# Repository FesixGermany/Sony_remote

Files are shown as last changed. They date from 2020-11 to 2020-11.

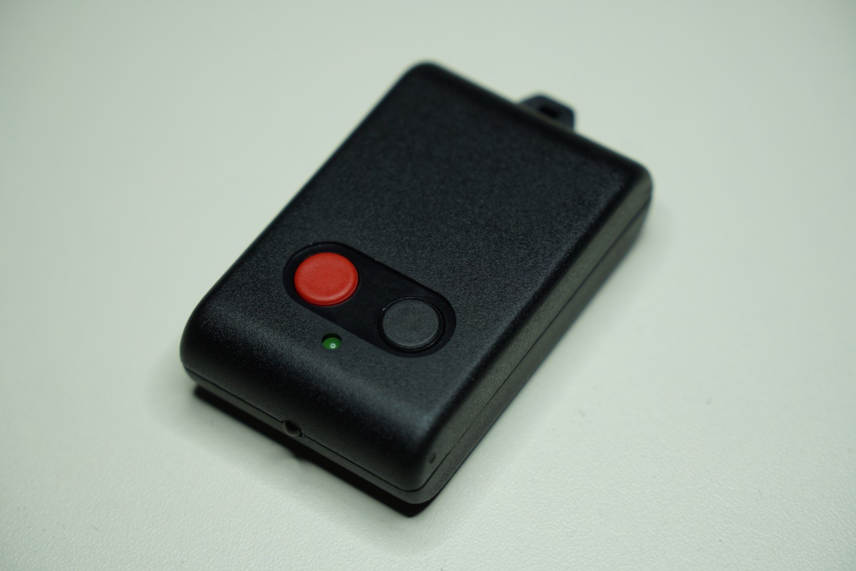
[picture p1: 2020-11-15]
documentation/Remote_case.jpg

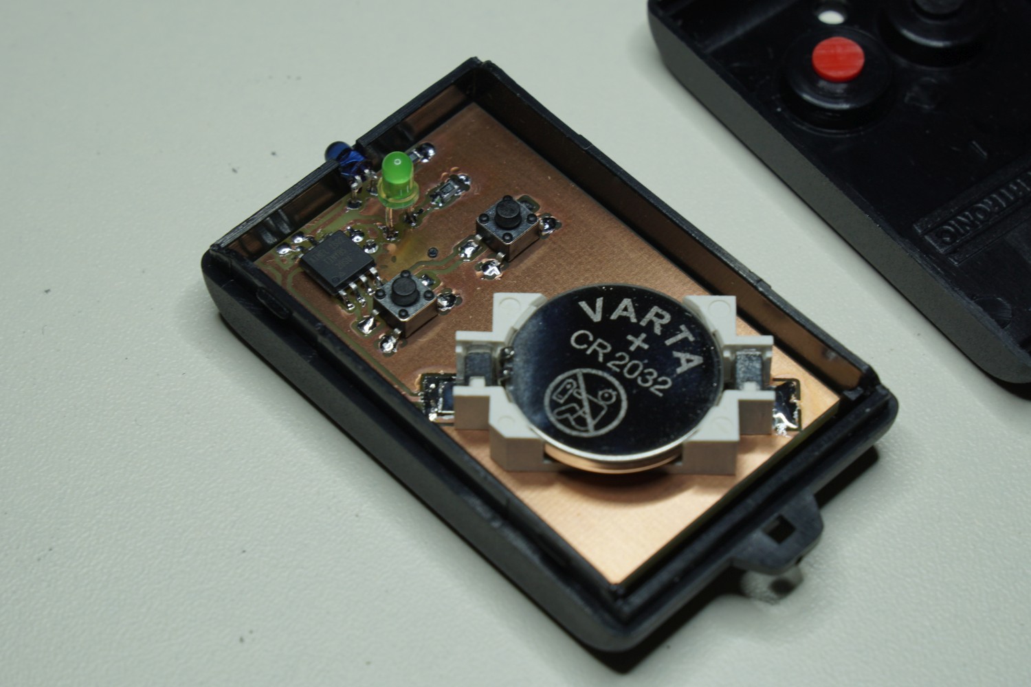
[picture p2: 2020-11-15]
documentation/Remote_inner.jpg

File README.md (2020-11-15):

I wanted a remote control for my Sony a6500 camera which has an IR receiver. There is a dedicated remote control with tons of buttons I don't need so I thought this would be a nice little project as all I need is a button for instant action and for a two second delay.  
Additionally the command for starting and stopping video recording is in the firmware so the functionality of the buttons can be changed.  
Exchange `ShutterCode` or `TwoSecsCode` with `VideoCode`.

```c
#define ButtonRightCode ShutterCode
#define ButtonLeftCode	TwoSecsCode
```

The whole circuit is powered by a 2032 button cell.  
The controller generates the necessary 40kHz modulation and sends the command set in the firmware when the button is pressed. As long as the command is transmitted the green LED is lit.
After that the controller goes into sleep mode to save battery.

In order to work with the camera the remote function needs to be enabled in the system menu.

The original code is from http://www.technoblogy.com/show?VFT

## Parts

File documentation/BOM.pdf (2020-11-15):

Segor Part No. | Digikey Part No. | Ammount | Reference | Value | Package | Additional Information
LZH 20-1 /SMD | 36-1060CT-ND (https://www.digikey.com/product-detail/en/keystone-electronics/1060TR/36-1060CT-ND/4935558) | 1 | BAT1 | | | For CR2032 battery
ATtiny 85-20SU | ATTINY85-20SURCT-ND (https://www.digikey.com/product-detail/en/microchip-technology/ATTINY85-20SUR/ATTINY85-20SURCT-ND/3789340) | 1 | IC1 | | SO-8
TSAL4400 | 751-1201-ND (https://www.digikey.com/product-detail/en/vishay-semiconductor-opto-division/TSAL4400/751-1201-ND/1681336) | 1 | LED1 | | 3mm
LED 3 gn-dif/3,0cd | no equivalent found | 1 | LED2 | diff. green 3cd | 3mm | Lower brightness than 3cd also okay, then R2 might have to be changed for lower value
100R-0805-1% | 311-100CRCT-ND (https://www.digikey.com/product-detail/en/yageo/RC0805FR-07100RL/311-100CRCT-ND/730490) | 1 | R1 | 100 | 0805
1k-0805-1% | 311-1.00KCRCT-ND (https://www.digikey.com/product-detail/en/yageo/RC0805FR-071KL/311-1-00KCRCT-ND/730391) | 1 | R2 | 1k | 0805
TACT 4545/4,3-SMD | EG5353TR-ND (https://www.digikey.com/product-detail/en/e-switch/TL3305AF260QG/EG5353TR-ND/5816184) | 2 | SW1, SW2
PP 24 sw | no equivalent found | 1 | Housing | | | Supertronic PP24

All parts for this project were sourced from Segor electronics Berlin (www.segor.de), Digikey Part No. should work but is not tested by me.

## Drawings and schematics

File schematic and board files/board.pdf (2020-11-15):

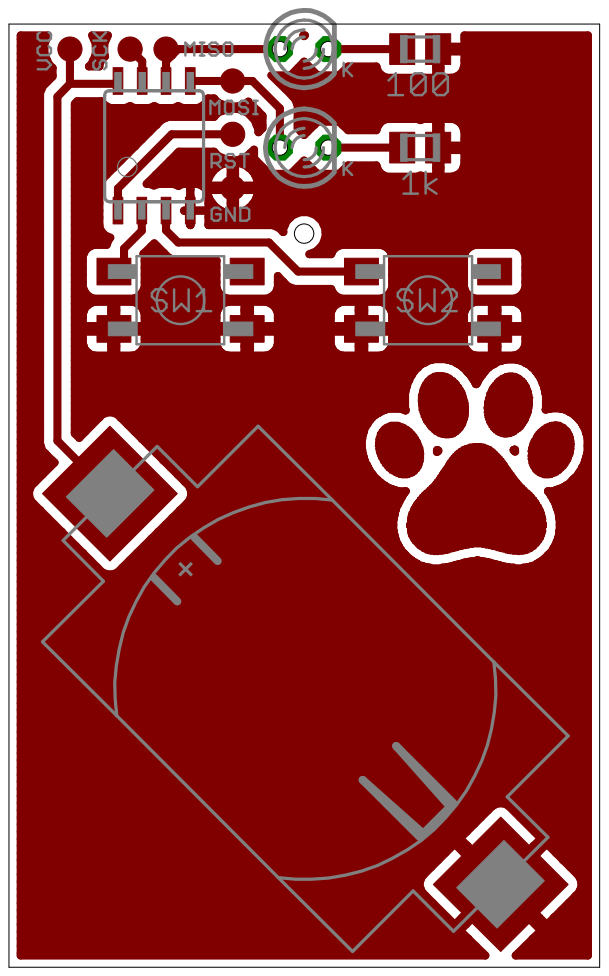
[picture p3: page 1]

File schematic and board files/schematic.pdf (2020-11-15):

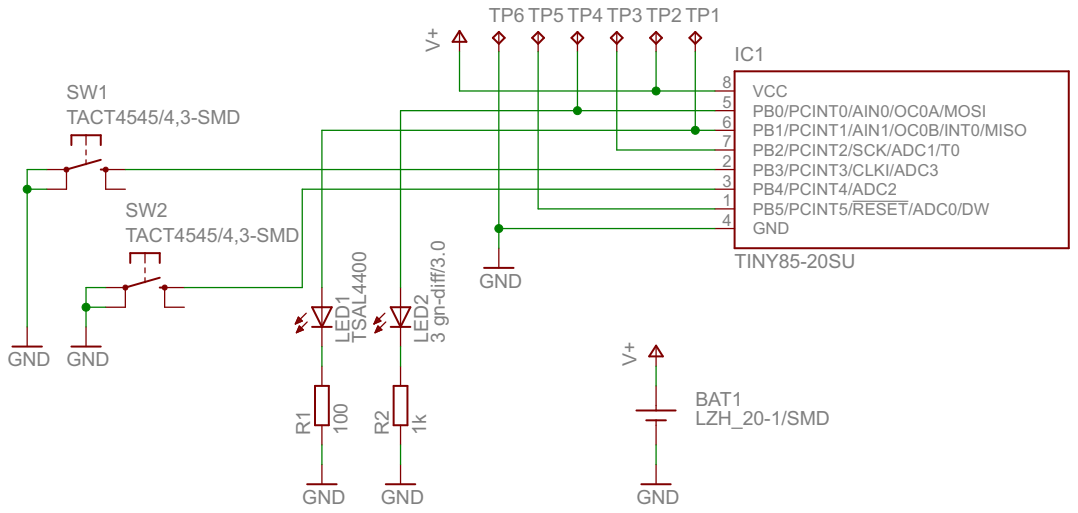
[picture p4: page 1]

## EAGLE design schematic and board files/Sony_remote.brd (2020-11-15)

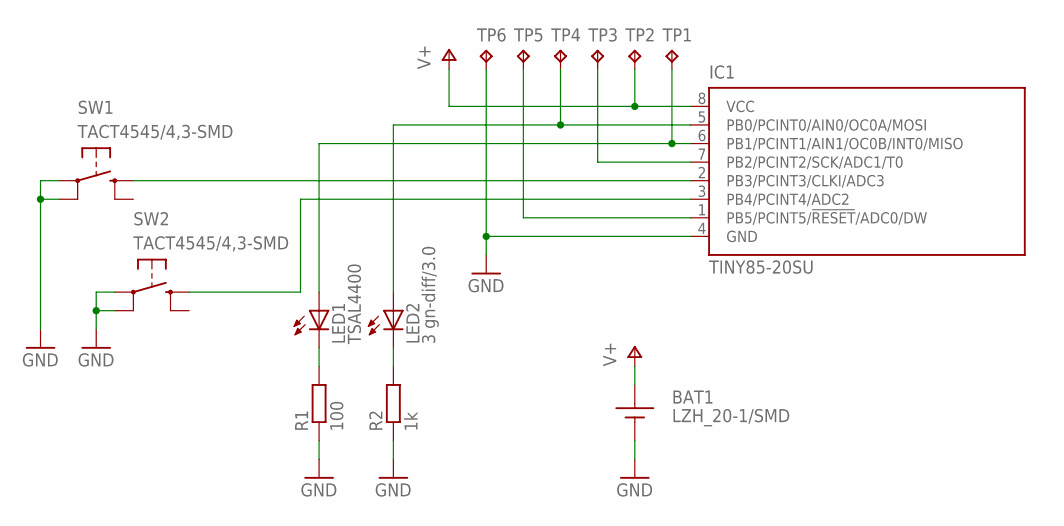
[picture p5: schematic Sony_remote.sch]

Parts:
BAT1: LZH_20-1/SMD
IC1: TINY85-20SU; 8S2
LED1: TSAL4400; LED3MM
LED2: 3 gn-diff/3.0; LED3MM
R1: 100; M0805
R2: 1k; M0805
SW1, SW2: TACT4545/4,3-SMD; TACT4545-SMD
TP1: MISO; B1,27
TP2: VCC; B1,27
TP3: SCK; B1,27
TP4: MOSI; B1,27
TP5: RST; B1,27
TP6: GND; B1,27

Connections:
GND: BAT1.-, IC1.4 (GND), R1.1, R2.1, SW1.P$1, SW1.P$2 (P1), SW2.P$1, SW2.P$2 (P1), TP6.TP
unnamed: IC1.2 (PB3/PCINT3/CLKI/ADC3), SW1.P$3 (S)
unnamed: IC1.7 (PB2/PCINT2/SCK/ADC1/T0), TP3.TP
unnamed: IC1.3 (PB4/PCINT4/ADC2), SW2.P$3 (S)
unnamed: IC1.5 (PB0/PCINT0/AIN0/OC0A/MOSI), LED2.A, TP4.TP
unnamed: IC1.6 (PB1/PCINT1/AIN1/OC0B/INT0/MISO), LED1.A, TP1.TP
unnamed: IC1.1 (PB5/PCINT5/!RESET!/ADC0/DW), TP5.TP
unnamed: LED1.K (C), R1.2
unnamed: LED2.K (C), R2.2
V+: BAT1.+, IC1.8 (VCC), TP2.TP

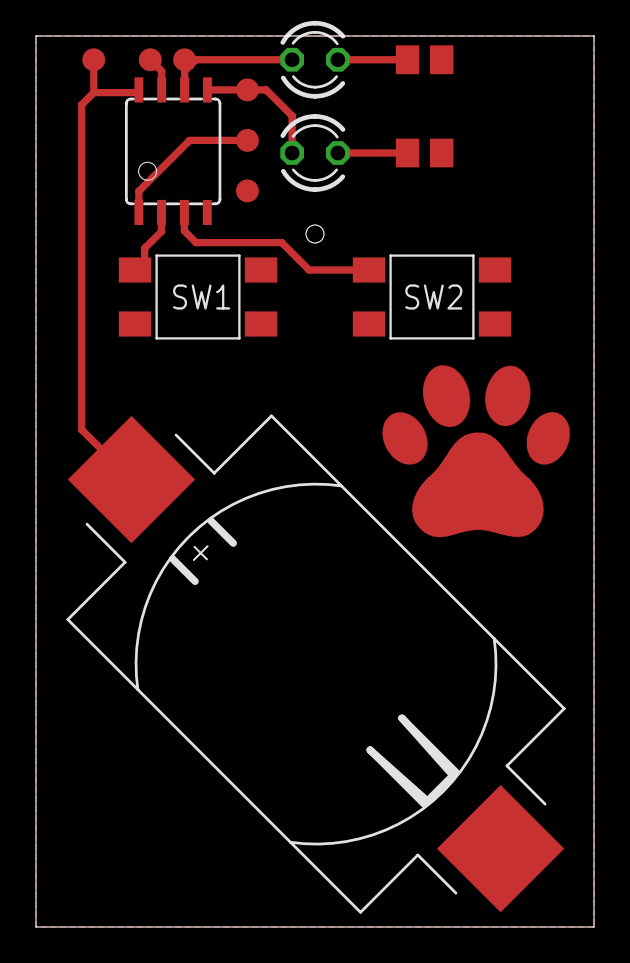
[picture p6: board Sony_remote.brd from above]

Board: 2 copper layers, 31.0 x 49.5 mm, 14 parts (0 on the bottom side), 10 nets.

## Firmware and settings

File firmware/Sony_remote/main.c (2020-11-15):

/*
 * ATtiny85 Sony NEX/Alpha Remote Control
 *
 * David Johnson-Davies - www.technoblogy.com - 12th April 2015
 * ATtiny85 @ 1 MHz (internal oscillator; BOD disabled)
 *
 * CC BY 4.0
 * Licensed under a Creative Commons Attribution 4.0 International license: 
 * http://creativecommons.org/licenses/by/4.0/
 *
 * 
 * Modified by Fesix
 * Converted from Arduino C to standard AVR C, some formatting of code and comments added.
 * Original code had a third button on PB5 for video, change defines as needed for functionality of buttons.
 * 
 * Original source: http://www.technoblogy.com/show?VFT
 *
 * Note: IR LED stays lit until one button is pressed the first time.
 *
 */ 

#include <avr/io.h>
#include <avr/sleep.h>
#include <avr/interrupt.h>

// Pin assignments
#define IRout 			PB1   // OC0B
#define ButtonRight		PB4
#define ButtonLeft		PB3
#define LED 			PB0

// Assign button functions, look next segment 'Remote Control' and replace as needed
#define ButtonRightCode ShutterCode
#define ButtonLeftCode	TwoSecsCode

// Remote control
const int Address = 0x1E3A;		// Destination of code
const int ShutterCode = 0x2D;	// Activate shutter without delay
const int TwoSecsCode = 0x37;	// Activate shutter with two second delay
const int VideoCode = 0x48;		// Start video recording

// IR transmitter *****************************************

const int top = 24;    // 1000000/25 = 40kHz
const int match = 18;  // pulses with approx 25% mark/space ratio

// Set up Timer/Counter0 to output PCM on OC0B
void SetupPCM ()
{
	TCCR0A |= (3 << COM0B0) | (3 << WGM00);				// Inverted output on OC0B and Fast PWM
	TCCR0B |= (1 << WGM02) | (1 << CS00);				// Fast PWM and divide by 1
	OCR0A = top;										// 40kHz
	OCR0B = top;										// Keep output low
}

// Set up pin change interrupts on button pins
void SetupPinChange ()
{
	PCMSK |= (1 << ButtonRight) | (1 << ButtonLeft);	// Pin change mask register
	GIMSK |= (1 << PCIE);								// Pin change interrupt enable
}

void Pulse (int carrier, int gap)
{
	int count = carrier;								// First send carrier pulses
	OCR0B = match;										// Generate pulses
	for (char i = 0; i < 2; i++)
	{
		for (int c = 0; c < count; c++)
		{
			do ; while ((TIFR & (1 << TOV0)) == 0);		// Counter0 overflow flag
			TIFR |= (1 << TOV0);
		}
		count = gap;									// Now send no pulses (gap)
		OCR0B = top;									// Output low because OCR0B equals OCR0A
	}
}

void SendSony (unsigned long code)
{
	TCNT0 = 0;											// Start counting from 0
	// Send Start pulse
	Pulse (96, 24);
	// Send 20 bits
	for (int Bit = 0; Bit < 20; Bit++)
	{
		if (code & ((unsigned long) 1<<Bit))			// If bit of code is 1
			Pulse (48, 24);
		else Pulse (24, 24);							// If bit of code is 0
	}
}

// Transmit code and light LED
void Transmit (int address, int command)
{
	unsigned long code = (unsigned long) address << 7 | command;	// Join address and command
	PORTB |= (1 << LED);								// Control LED on begin transmit
	SendSony (code);									// Send code
	Pulse (0, 430);										// Wait 11ms and send again (430*25us)
	SendSony (code);
	Pulse (0, 430);										// Wait 11ms and send again (430*25us)
	SendSony (code);
	PORTB &= ~(1 << LED);								// Control LED off transmit complete
}

// Interrupt **********************************************

// Use PCINT0 just to wake up from sleep
ISR (PCINT0_vect)
{
}

 
 // Main program ******************************************
 
 int main (void)
 {
	 DDRB &= ~(1 << ButtonRight) | ~(1 << ButtonLeft);	// Inputs
	 PORTB |= (1 << ButtonRight) | (1 << ButtonLeft) ;	// Internal pullups for buttons
	 DDRB |= (1 << IRout) | (1 << LED);					// Outputs
	 
	 set_sleep_mode(SLEEP_MODE_PWR_DOWN);				// MCUCR |= (1 << SM1);
	 
	 ADCSRA &= ~(1<<ADEN);								// Disable ADC to save power
	 
	 SetupPCM(); 
	 SetupPinChange();
	 
	 // Main loop
	 while (1)
	 {
		// Go to sleep
		sleep_enable();									// Equals MCUCR |= (1 << SE);
		sei();
		sleep_cpu();
		
		// Come here after pin change interrupt wakes us from sleep
		// Check which button is pressed and transmit
		if (!(PINB & (1 << ButtonRight)))
			Transmit (Address, ShutterCode);
		else if (!(PINB & (1 << ButtonLeft)))
			Transmit (Address, TwoSecsCode);
		// Wait for all buttons to be released
		do ; while (!(PINB & (1 << ButtonRight)) || !(PINB & (1 << ButtonLeft)));
	}
}
